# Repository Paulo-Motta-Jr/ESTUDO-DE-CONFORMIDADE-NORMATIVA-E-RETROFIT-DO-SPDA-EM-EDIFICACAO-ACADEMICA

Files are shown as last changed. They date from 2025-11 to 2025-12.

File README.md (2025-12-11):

# ESTUDO DE CONFORMIDADE NORMATIVA E RETROFIT DO SISTEMA DE PROTEÇÃO CONTRA DESCARGAS ATMOSFÉRICAS (SPDA) EM EDIFICAÇÃO ACADÊMICO: AVALIAÇÃO E ADEQUAÇÃO ÀS NORMAS ABNT NBR 5419:2015


**Curso: Engenharia Elétrica**

**Trabalho realizado por:**

José Carlos Franchini Junior  - email: jose.franchini@alunos.fho.edu.br

Paulo Ijano Motta Junior - email: paulomotta@alunos.fho.edu.br

**Orientado por:**

Prof. Dr. Daniel Augusto Pagi Ferreira - email: danielferreira@fho.edu.br

🛡️ **Retrofit do SPDA – Restaurante FHO**

Projeto desenvolvido para avaliar o SPDA existente do restaurante da FHO, identificar falhas e propor um novo sistema totalmente alinhado à ABNT NBR 5419:2015. O estudo envolveu inspeção técnica, análise de risco, modelagem 3D e redimensionamento completo dos subsistemas de captação, descida, aterramento e proteção interna.

🔍 **Escopo do Projeto**

-Levantamento técnico e análise das condições atuais do SPDA.

-Identificação de não conformidades: seção insuficiente de condutores, oxidação, falta de equipotencialização e ausência de DPS.

-Modelagem da edificação no AutoCAD Plant 3D para precisão geométrica.

-Análise de risco com o software TUPAN, definindo a Classe de Proteção adequada.

-Aplicação do método da Esfera Rolante para definição da zona de proteção.

-Dimensionamento de nova captação, inclusão de captores individuais para exaustores e redistribuição das descidas.

-Correção do sistema de aterramento e inclusão de equipotencialização das estruturas metálicas.

📈 **Resultados Obtidos**

-SPDA redesenhado conforme todos os requisitos da ABNT NBR 5419.

-Sistema mais seguro, padronizado e com maior confiabilidade.

-Riscos estruturais e elétricos significativamente reduzidos.

-Garantia de proteção externa e interna através de DPS e conexões equipotenciais.

-Projeto final completo, com layouts precisos e pronto para execução.

  Imagem1
</p>

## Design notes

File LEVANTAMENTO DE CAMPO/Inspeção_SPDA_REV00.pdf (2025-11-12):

0 | ITEM ANALISADO | CONSIDERAÇÕES

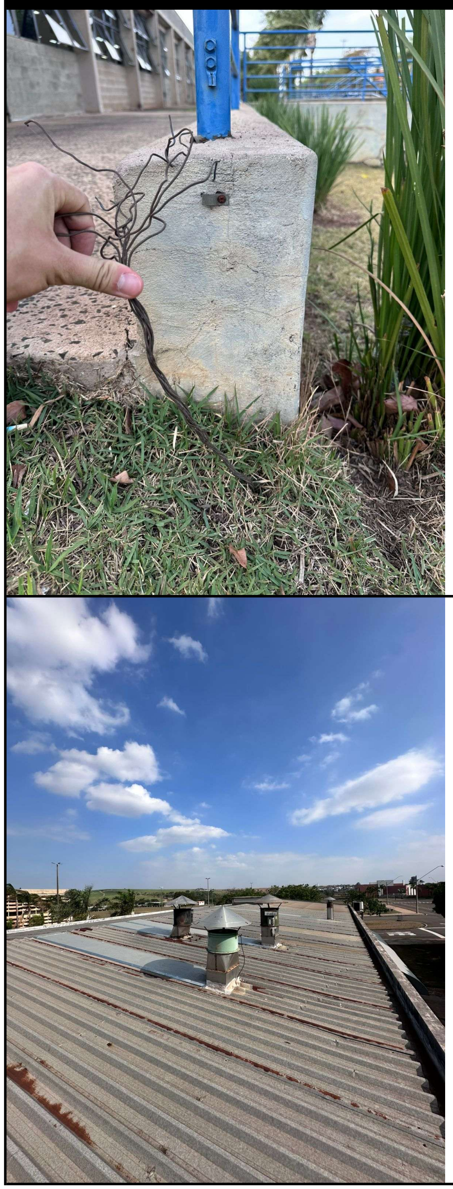
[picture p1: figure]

MALHA DE ATERRAMENTO

*Malha de aterramento rompida.
*Abertura na malha de equipotencialização dos guarda-corpos da escada de acesso ao
restaurante.

EXAUSTORES DE COCÇÃO

*Equipamento em altitude mais elevada do que o
captor natural.
* Equipamento sendo usado como captor natural, porém, em uma eventual decarga atmosférica ele poderá ser danificado podendo causar avarias na instalação interna e externa.

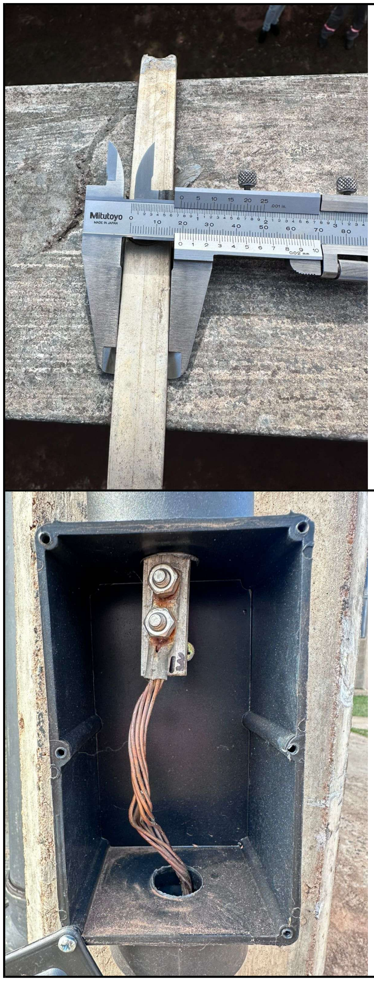
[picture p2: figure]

BARRA CHATA DE ALUMÍNIO

*Barra chata em desconformidade com a norma NBR 5419-3:2015 Tabela 6 (área de seção mínima).
Espessura medida: 3mm
Largura medida: 19mm
Área de seção minima: 57mm²

Área de seção mínima exigida pela norma: 70mm²

CAIXA DE INSPEÇÃO
(SPDA)

*Oxidação evidente entre o terminal e a barra chata podendo ocasionar em resistividade maior(oposição) á descarga atmosférica.
*Malha de aterramento cobreada em conformidade com as especificações técnicas (7 fios).

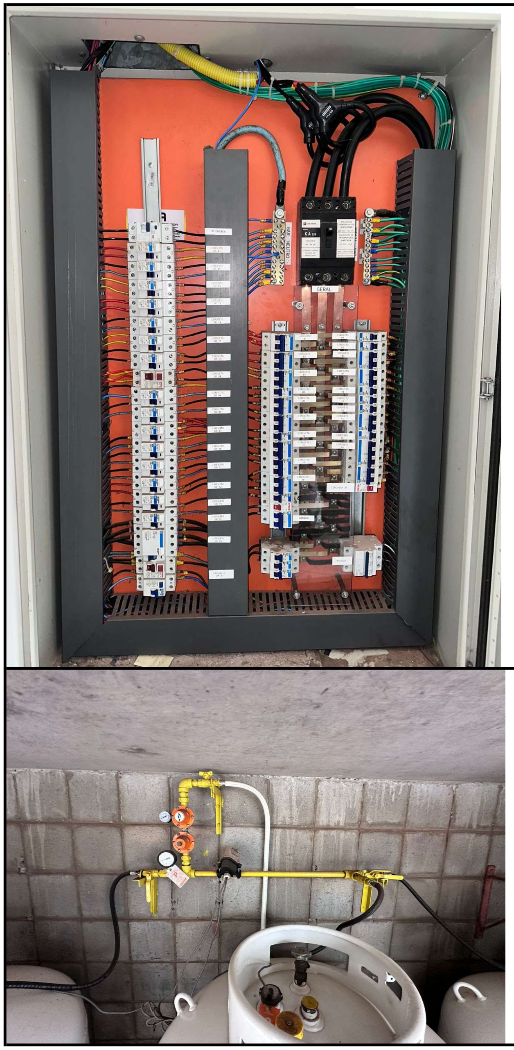
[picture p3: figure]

PAINÉIS DE DISTRIBUIÇÃO
QDT-01 e QDT-02

*Observado a falta de Dispositivos de proteção contra-surtos (DPS) - SPDA interno - itens exigidos pela NBR 5419-4:2015 para essa classificação de risco.

Obs: Pela classificação de risco realizada durante o desenvolvimento do projeto, deveriam exitir DPS's classe II.

INFRAESTRUTURA DE GÁS GLP *Ausência de equipotencialização desse sistema com a malha aterramento, o que pode gerar risco de centelhamento e consequentemente incêndio.

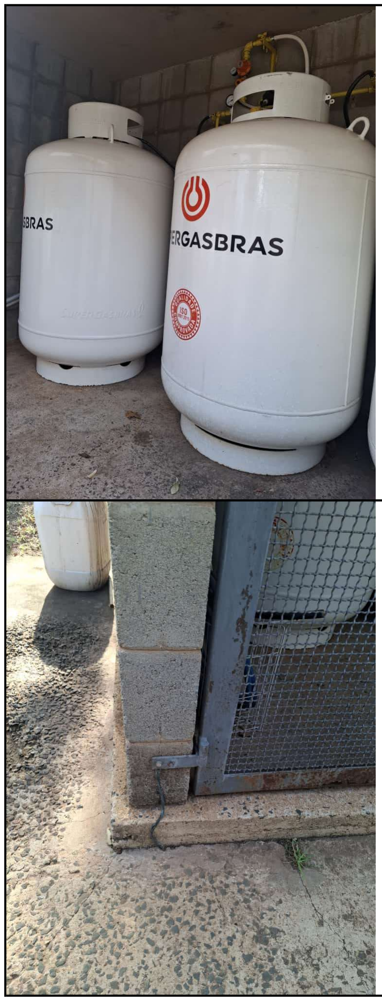
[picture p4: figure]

BOTIJÕES DE GÁS GLP | *Ausência de equipotencialização dos botijões com a malha de aterramento, o que pode gerar risco de centelhamento e consequentemente incêndio.

ÁREA DE ARMAZENAMENTO
DE GÁS GLP | * Todos os portões estão equipotencializadas com a malha de aterramento.

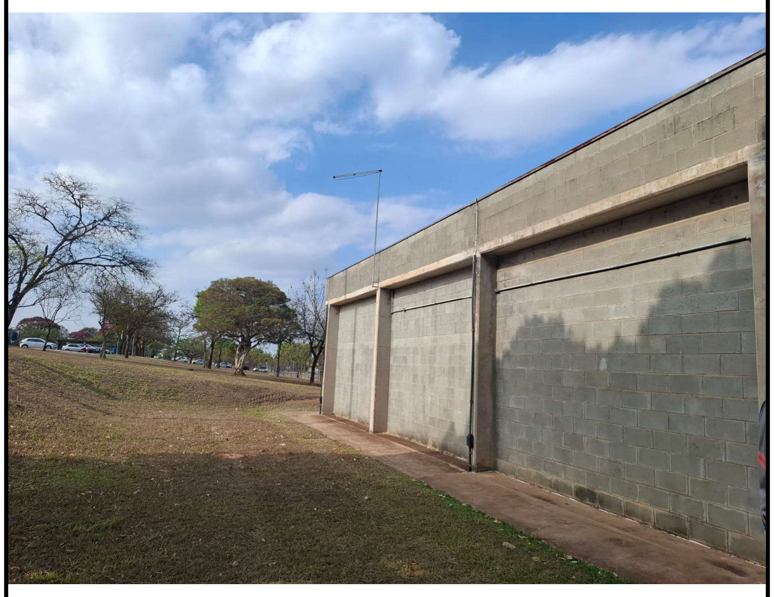
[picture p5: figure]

SUBSISTEMA DE DESCIDA
(SPDA)

*Distância medida entre descidas(inferior a 5m) em conformidade com a NBR 5419-3:2015 (mínimo de 20m).
*Durante a vistoria, foi identificado que o projeto antigo de SPDA da estrutura foi interligado ao novo sistema instalado, que utiliza captação natural. Essa junção resultou na equipotencialização entre os dois sistemas. No entanto, essa integração pode ser prejudicial, pois altera a impedância do conjunto. Com isso, em caso de uma descarga atmosférica, a corrente pode seguir caminhos diferentes dos previstos no projeto, comprometendo a eficácia e a segurança da proteção contra descargas atmosféricas.

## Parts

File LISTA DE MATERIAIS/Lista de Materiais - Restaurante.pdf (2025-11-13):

Item | Descrição dos serviços | Unid. | Quant.

## 1 SERVIÇOS PRELIMINARES

1.1 | Tapumes e Fitas de Isolamento da Obra | - | 1,00
1.2 | Anotação de Responsabilidade Técnica da Obra | - | 1,00
1.3 | Segurança do trabalho e proteções coletivas, o seguro dos próprios equipamentos e a responsabilidade civil. | - | 1,00
1.4 Mão de obra para realização de teste de continuidade nos cabos elétricos de aterramento, considerando execução | de relatório fotográfico; | - | 1,00
1.5 | Mão de obra, para abertura e fechamento de valas | - | 1,00
1.6 | Mão de obra, equipamentos e materiais para reparação da estrutura civil danificada. | - | 1,00
1.7 Mão de obra e fornecimento de materiais de miscelâneas (parafusos / porcas / arruelas / buchas / chumbadores / fita | hellermann / identificadores de cabos / etc.) | - | 1,00
1.8 | Prever a realização de anotações para as - built do projeto. | - | 1,00

## 2 SPDA / ATERRAMENTO

## 2.1 ESTRUTURA ENTERRADA

2.1.1 Haste cobreada alta camada Ø3/4"x3,0m | Referência:TEL - 5823 (Termotécnica) | un | 2,00
2.1.2 Cabo de cobre nu 50 mm² 7 FIOS X Ø3 mm (NBR6524); Ø cordoalha: 9,00 mm; CLASSE A; RESIST. ELÉTRICA | MÁXIMA A 20°C: 0,375 Ω/km; | m | 196,00
2.1.3 Alicate Z-201 (para solda exotérmica) | Referência: (Exosolda) | un | 1,00
2.1.4 Cartucho n° 90 para solda exotérmica | Referência: (Exosolda) | un | 10,00
2.1.5 Cartucho n° 115 para solda exotérmica | Referência: (Exosolda) | un | 2,00
2.1.6 | Molde para solda exotérmica tipo CDH (cabo de 50mm² / cabo de 50mm²) - cartucho N° 90 Referência: CDH 50.50-3 (Exosolda) | un | 1,00
2.1.7 | Molde para solda exotérmica tipo HCL (haste de 3/4" / cabo de 50mm²) - cartucho N°115 Referência: HCL 3/4.50-5 (Exosolda) | un | 1,00

## 2.2 ESTRUTURA AÉREA

2.2.1 Minicaptor 7/8"x1/8"x600mm | Referência: TEL-940 (Termotécnica) | un | 21,00
2.2.2 Minicaptor horiz. barra redonda DN=10mm H=1000 | Referência: TEL-2060 (Termotécnica) | un | 4,00
2.2.3 Minicaptor vertical barra redonda DN=10mm H=600 | Referência: TEL-2057 (Termotécnica) | un | 4,00
2.2.4 | Suporte equalizador colável alumínio com tela inox / Suporte fixador colável ADERIBASE ® em Alumínio com tela inox, afastamento 40mm, parafuso Ø 1/4” Referência: TEL-757 (Termotécnica) | barra | 205,00
2.2.5 | Adesivo monocomponente a base de poliuretano para superfícies lisas (bisnaga 290ml). Para uso em superfícies lisas, polidas ou metálicas. (para fixação do aderibase - rendimento aprox. 20 apl) Referência: TEL-5907 (Termotécnica) | un | 12,00
| Barra chata em alumínio 7/8"x1/8", seção 70mm² com furos de ø7mm (barra 3m) - considerar parafuso e porca para fixação; Referência: TEL-770 (Termotécnica) | barra | 67,00
2.2.6

# LISTA DE MATERIAIS - SPDA FHO - RESTAURANTE

## MATERIAIS E SERVIÇOS DE MONTAGEM ELÉTRICA

Item | Descrição dos serviços | Unid. | Quant.
2.2.7 | Curvas horizontais 90º em alumínio 7/8″ x 1/8″ x 300mm (70mm²) – com furos - considerar parafuso e porca para fixação; Referência: TEL-782 (Termotécnica) | un | 6,00
2.2.8 | Adesivo monocomponente a base de poliuretano, tixotrópico: pré-polímero de poliuretano com silano modificado, sílica amorga, carga mineral, di-isononyl, pigmento e catalisador. (bisnaga 0,380kg). Para preenchimento de juntas de dilatação, vedação, acabamento e colagens deiversas. (para vedação dos furos das barras chatas fixadas nas platibandas - rendimento aprox. 4,5 metros linear) Referência: TEL-5905 (Termotécnica) | un | 10,00
2.2.9 | Terminal estanhado 1 furo 1 compressão, para cabos de #50mm²; (para conexão entres descidas de barra chata de alumínio e cabo de cobre nu 50mm²) Referência: TEL-5150 (Termotécnica) | un | 10,00
2.2.11 Condutor CUI 50mm² COMPRIMENTO 5m | Referência: TEL-830218 (Termotécnica) | un | 8,00
2.2.12 Abraçadeira para condutor CUI em poliamida com furo da base Ø6,5mm h=19mm | Referência: TEL-275220 (Termotécnica) | un | 30,00

# LISTA DE MATERIAIS - SPDA FHO - RESTAURANTE

## MATERIAIS E SERVIÇOS DE MONTAGEM ELÉTRICA

## 3 LIMPEZA E DESMOBILIZAÇÃO

3.1 | Limpeza periódica da obra | - | 1,00
3.2 | Limpeza final da obra | - | 1,00
3.3 | Desmobilização | - | 1,00

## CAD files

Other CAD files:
PROJETO AUTOCAD PLANT 3D/DWG/2025-PA-E-0-002 -Frontal e Lateral.dwg
PROJETO AUTOCAD PLANT 3D/DWG/2025-PA-E-0-001 - Planta.dwg

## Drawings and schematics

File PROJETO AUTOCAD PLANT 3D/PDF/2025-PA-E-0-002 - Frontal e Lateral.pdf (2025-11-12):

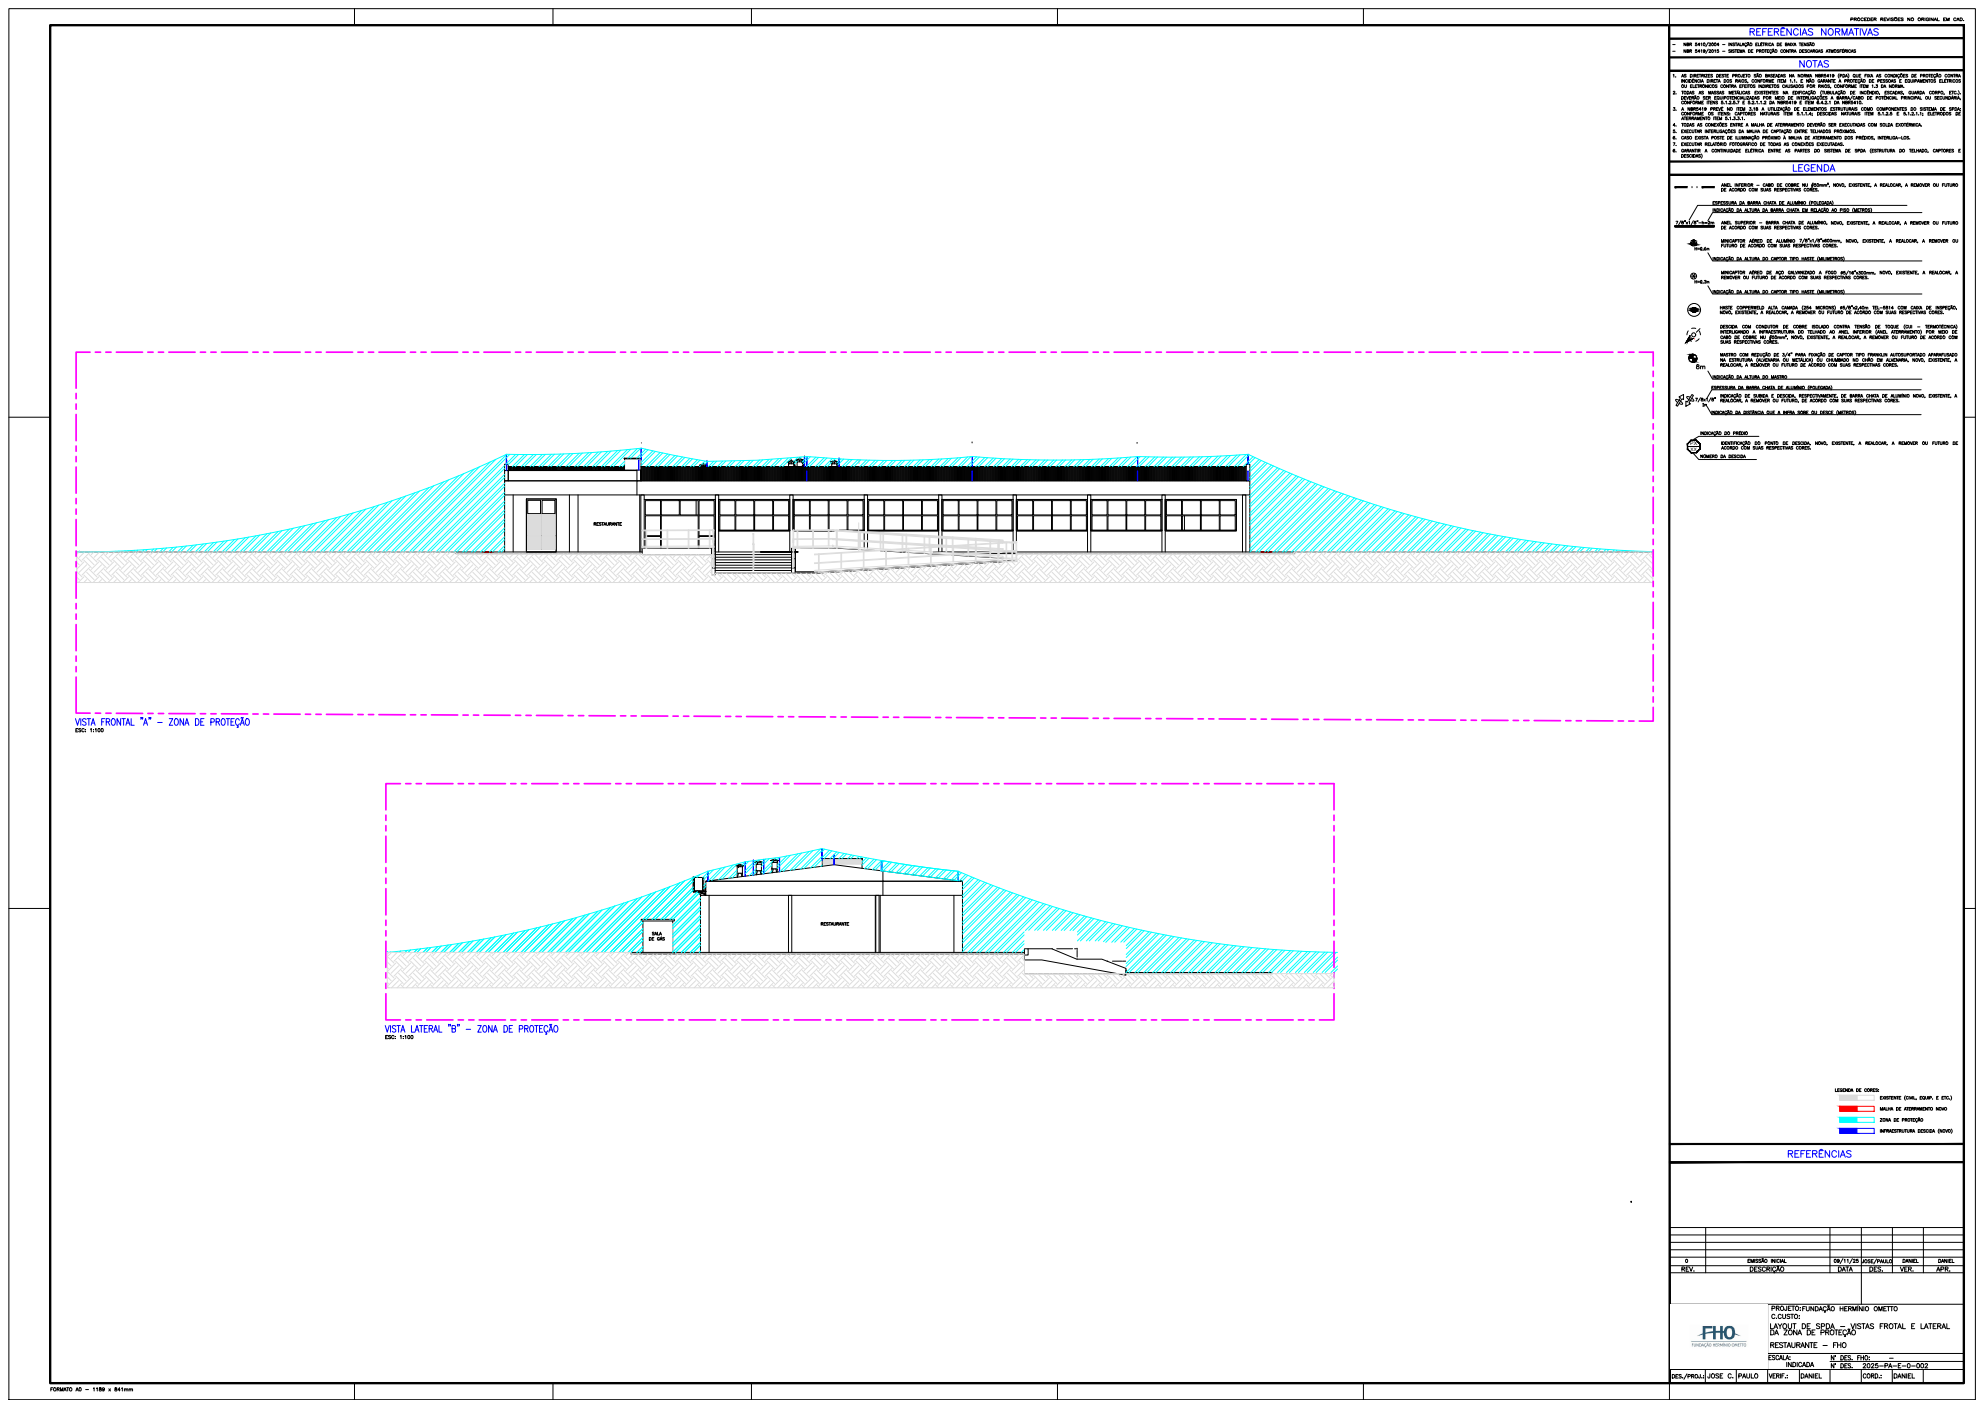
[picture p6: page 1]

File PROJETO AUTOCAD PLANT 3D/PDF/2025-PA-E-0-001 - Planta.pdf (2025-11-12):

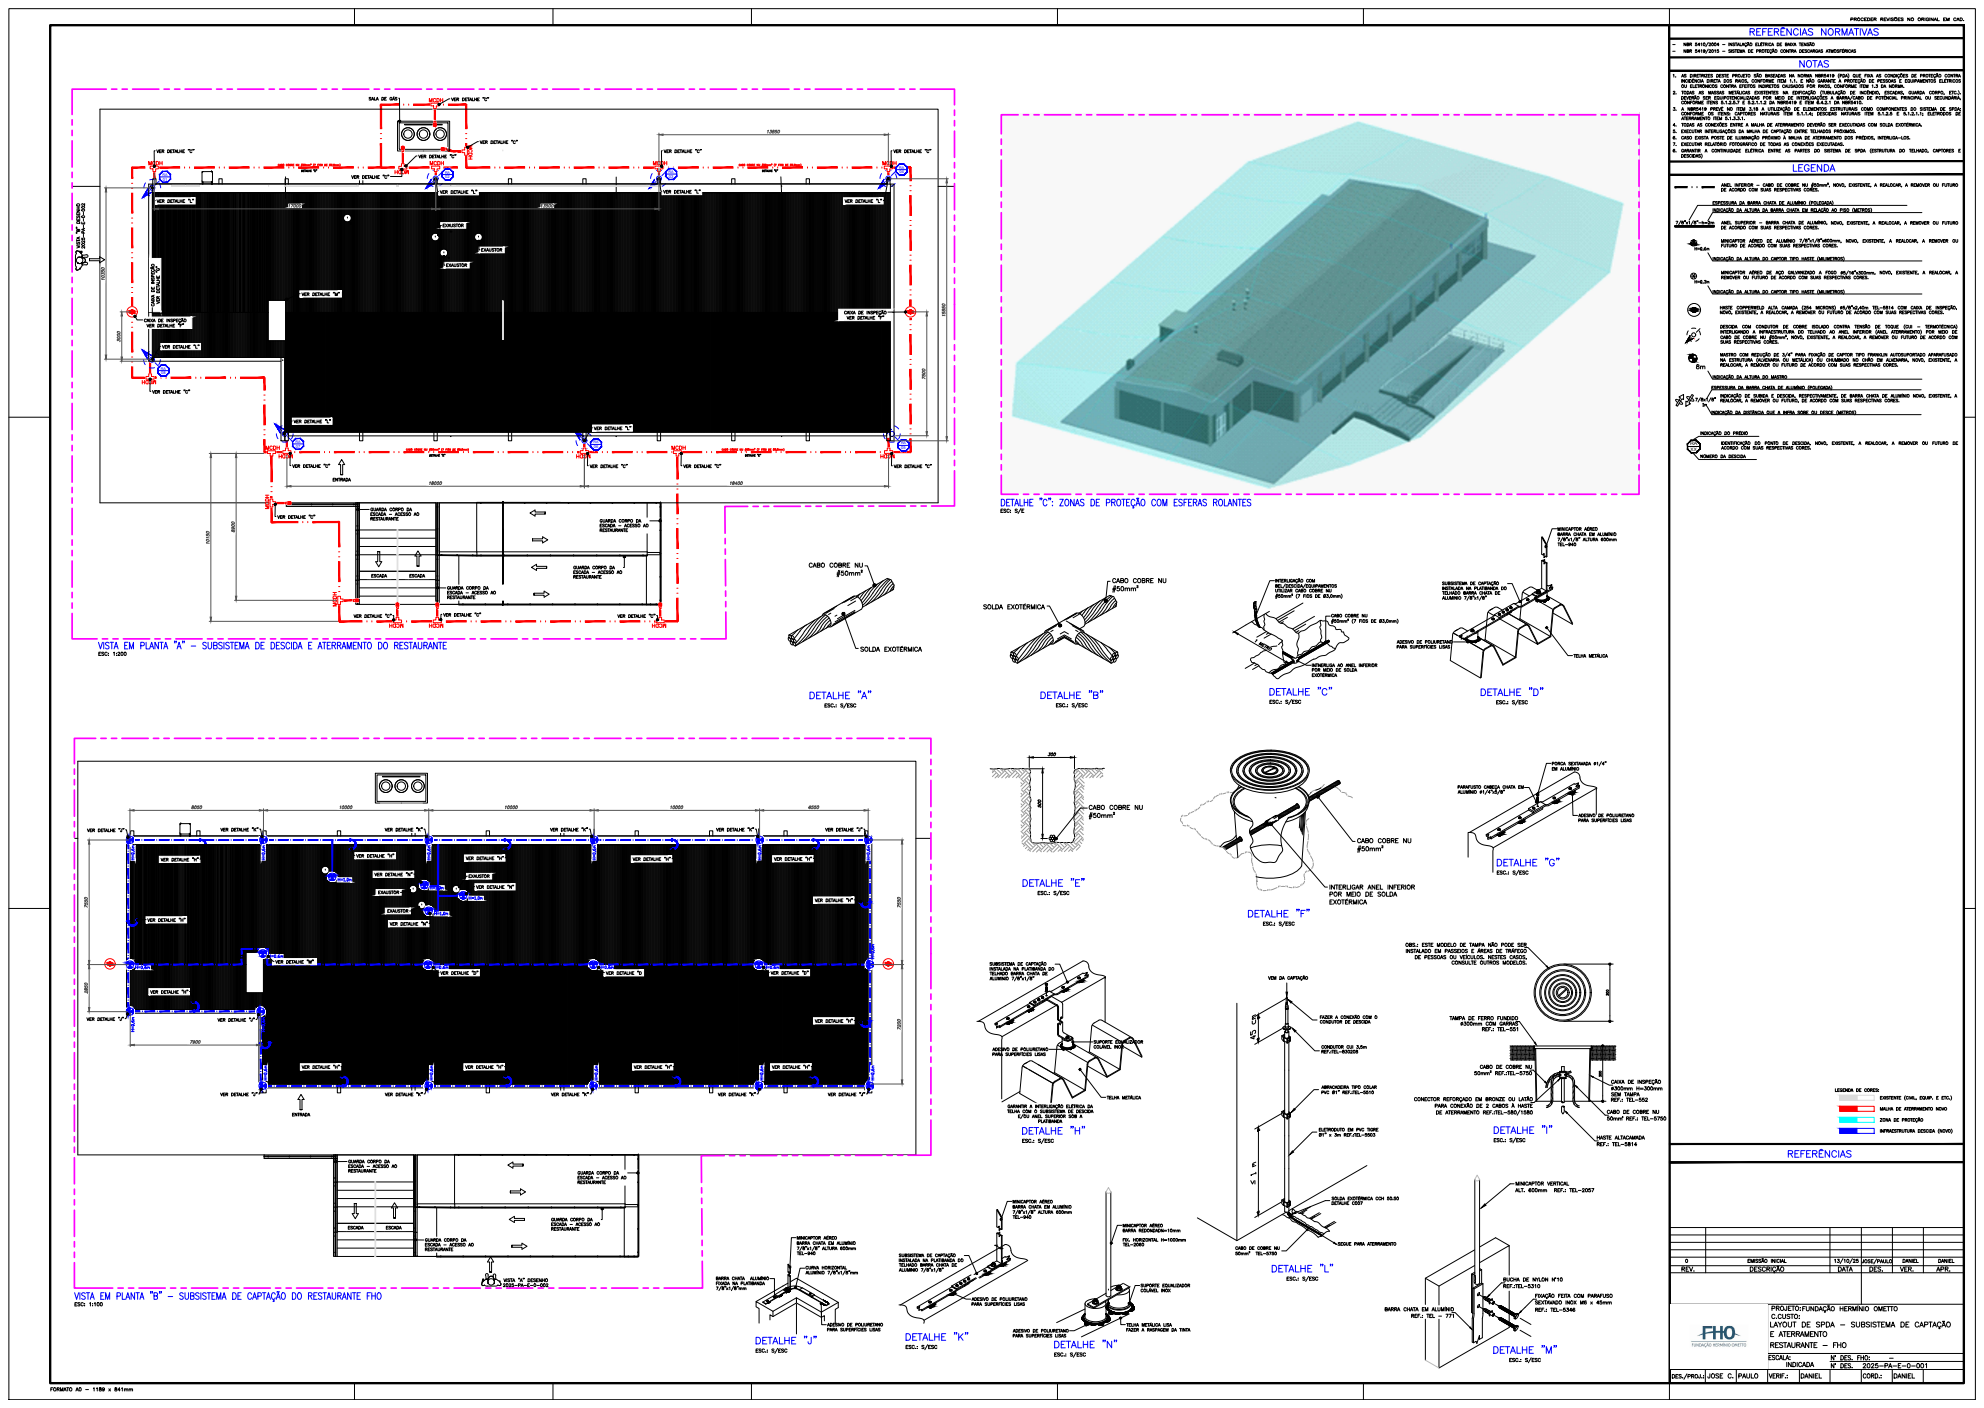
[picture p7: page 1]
XXRA

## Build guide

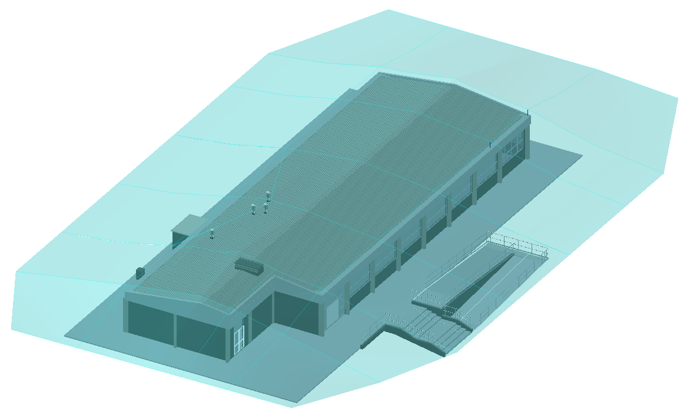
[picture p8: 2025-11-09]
PROJETO AUTOCAD PLANT 3D/Prints/Captura de tela 2025-10-17 235559.png

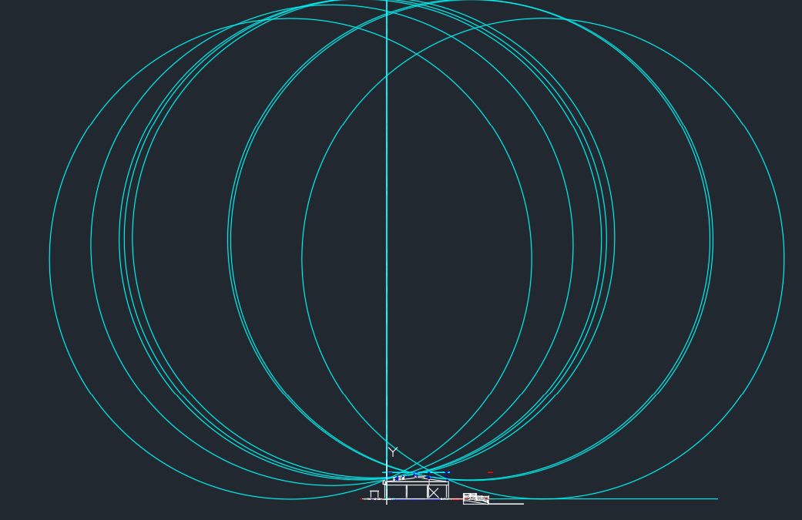
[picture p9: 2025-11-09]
PROJETO AUTOCAD PLANT 3D/Prints/Captura de tela 2025-11-09 194613.png

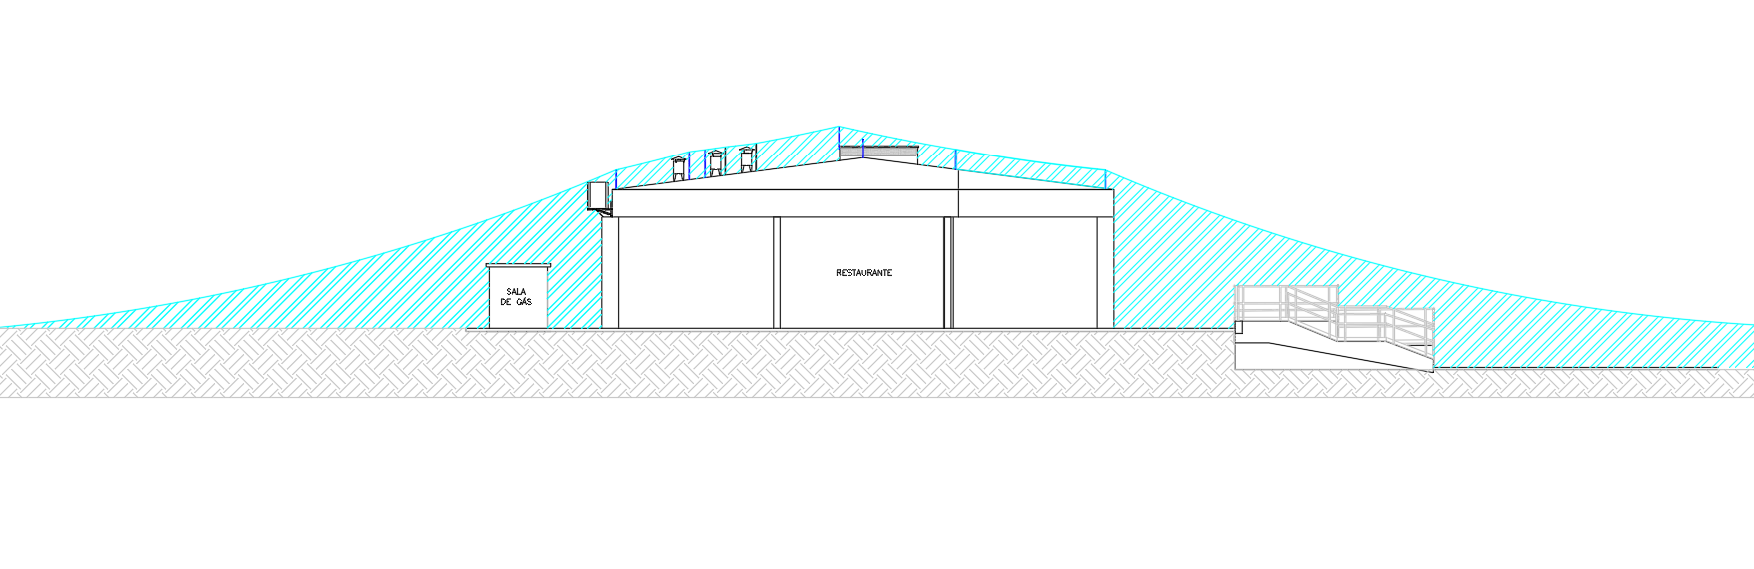
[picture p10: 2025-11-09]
PROJETO AUTOCAD PLANT 3D/Prints/Captura de tela 2025-11-09 172340.png

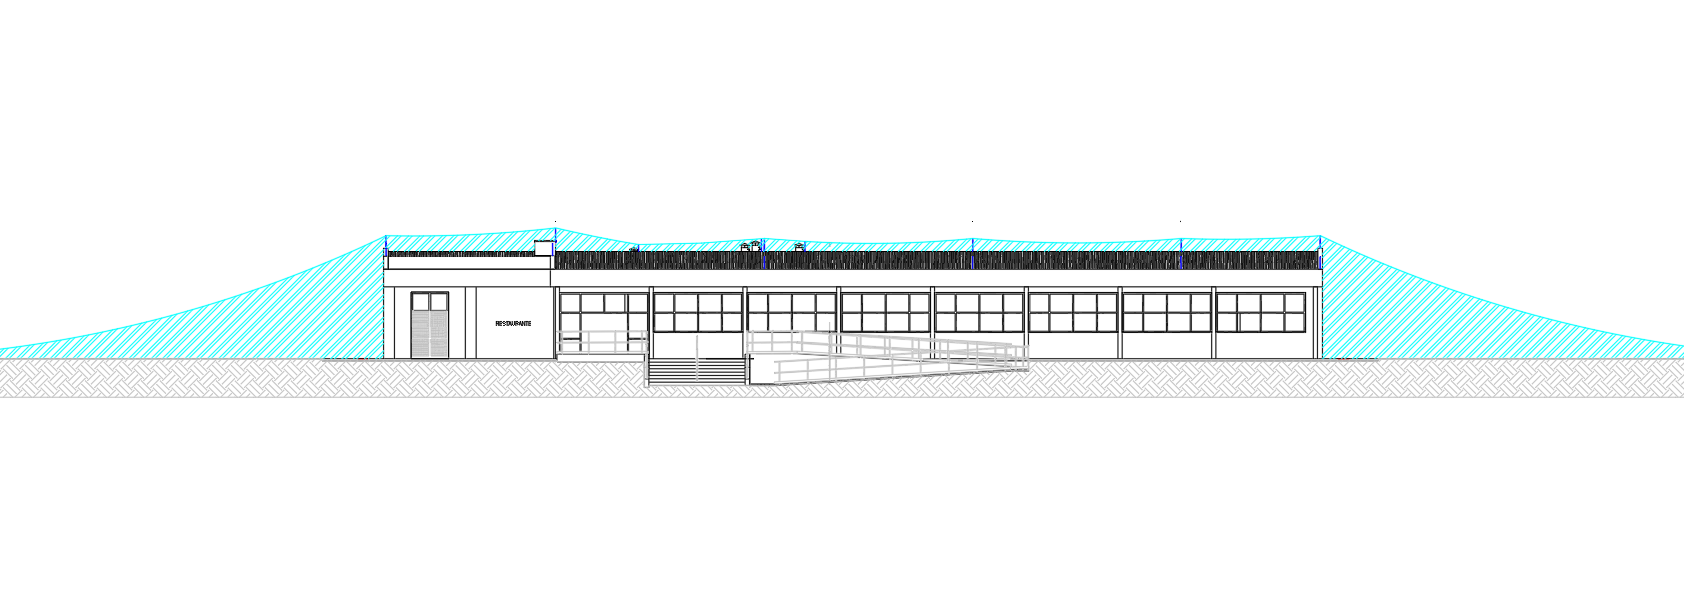
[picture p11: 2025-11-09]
PROJETO AUTOCAD PLANT 3D/Prints/Captura de tela 2025-11-09 172215.png

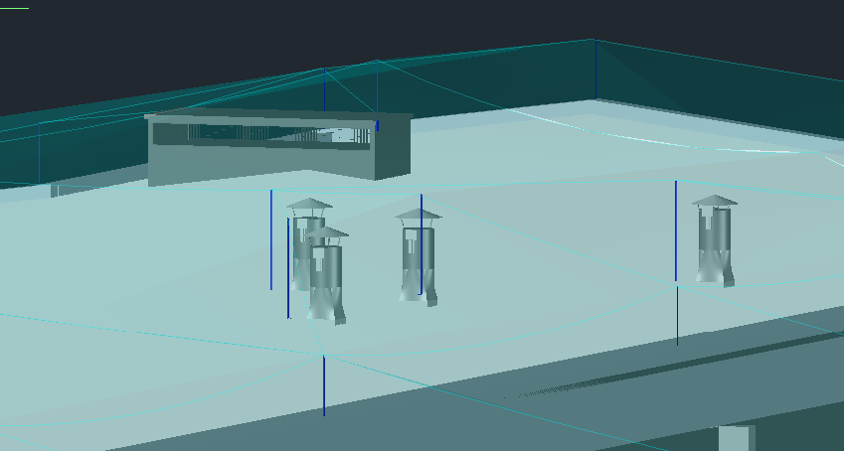
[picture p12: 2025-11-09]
PROJETO AUTOCAD PLANT 3D/Prints/Captura de tela 2025-10-17 230452.png

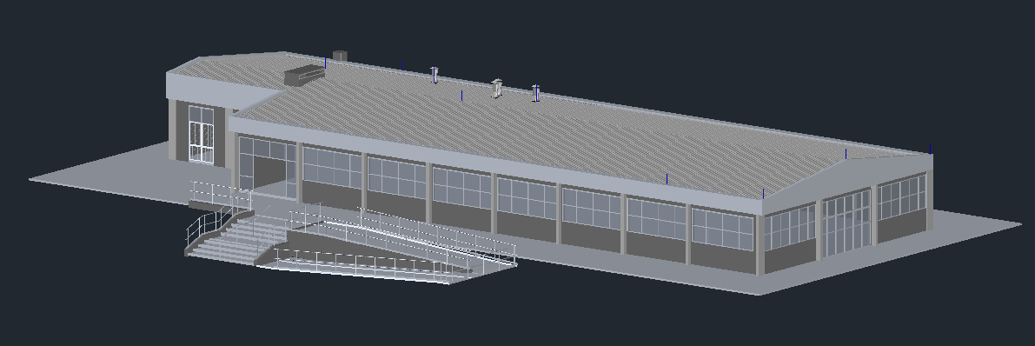
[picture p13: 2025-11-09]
PROJETO AUTOCAD PLANT 3D/Prints/Captura de tela 2025-10-18 000105.png
